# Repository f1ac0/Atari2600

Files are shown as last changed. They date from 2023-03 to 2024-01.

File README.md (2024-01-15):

# Atari2600
Inside the lot I bought to get my first C64 was also and Atari 2600. It was also listed as "Untested", and it was obviously salvaged from a flood considering the mud and rust that was inside the case. It came without any game or accessory.

While waiting for the system to dry after a complete clean and rust removal I found the useful projects below to help me start with this system I didn't know anything about.
- First I needed some game so I put together a ROM cartridge on a breadboard and created a PCB from it.
- Then not a single TV receiver I had could tune the video and audio signals correctly, but a BT848 PCTV PCI card. The mod by Eddy Foucault worked perfectly, I made my own version with CMS components and 5v only.
- At last I removed the regulator to power the console from a modern 5V power source.

In this repository are the PCBs I created or modified for my own needs.

# Disclaimer and Acknowledgements
This is a hobbyist project, it comes with no warranty and no support. Also remember that the 40 years old hardware may fail because of such expansions.

I publish my work under the CC-BY-NC-SA license, unless stated otherwise. Thanks to everyone who share their knowledge and creations.

# Useful links

## Cartridge
- https://github.com/sarweiler/a2k6-cart
- https://github.com/robinhedwards/UnoCart-2600
- https://github.com/DirtyHairy/UnoCart-2600/releases
- https://github.com/rglenn/unocart2600-pcb
- https://github.com/Al-Nafuur/United-Carts-of-Atari

## Video SECAM Atari 2600 to RGB SCART TV
- http://eddystoys.blogspot.com/2014/08/atari-2600.html

## Video SECAM to PAL
- https://forums.atariage.com/topic/245189-converting-a-secam-atari-2600-to-pal-or-ntsc/

## Video PAL/NTSC to composite
- https://www.arcticretro.com/2021/03/27/atari-2600-composite-video-mod/
- https://www.instructables.com/ATARI-2600-Video-Composite-mod/

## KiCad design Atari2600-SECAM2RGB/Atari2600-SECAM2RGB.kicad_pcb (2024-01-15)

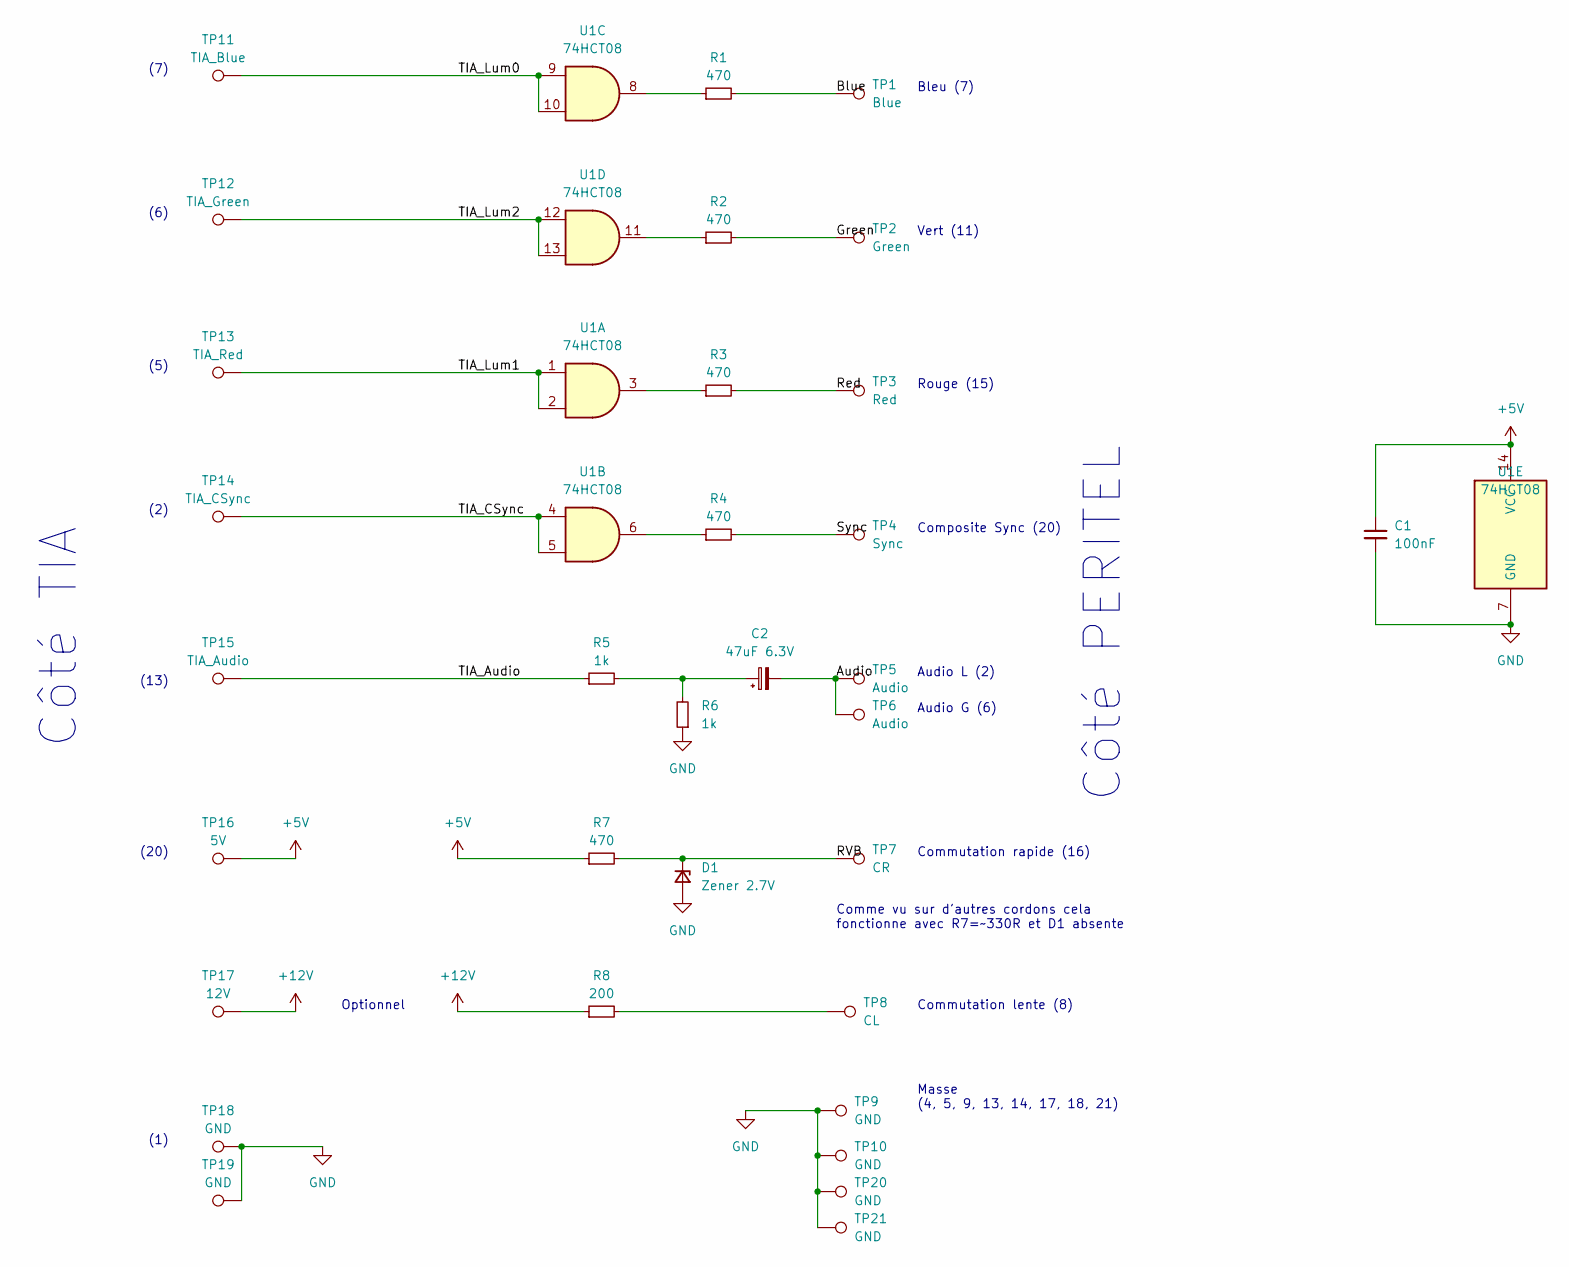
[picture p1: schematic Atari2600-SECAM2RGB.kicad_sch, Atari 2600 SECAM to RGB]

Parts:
C1: 100nF; C_0805_2012Metric
C2: 47uF 6.3V; CP_Elec_6.3x5.4
D1: Zener 2.7V; D_0805_2012Metric
R1, R2, R3, R4, R7: 470; R_0805_2012Metric
R5, R6: 1k; R_0805_2012Metric
R8: 200; R_0805_2012Metric
TP1: Blue; TestPoint_THTPad_D1.7mm_Drill1.0mm
TP2: Green; TestPoint_THTPad_D1.7mm_Drill1.0mm
TP3: Red; TestPoint_THTPad_D1.7mm_Drill1.0mm
TP4: Sync; TestPoint_THTPad_D1.7mm_Drill1.0mm
TP5, TP6: Audio; TestPoint_THTPad_D1.7mm_Drill1.0mm
TP7: CR; TestPoint_THTPad_D1.7mm_Drill1.0mm
TP8: CL; TestPoint_THTPad_D1.7mm_Drill1.0mm
TP9, TP10, TP18, TP19, TP20, TP21: GND; TestPoint_THTPad_D1.7mm_Drill1.0mm
TP11: TIA_Blue; TestPoint_THTPad_D1.7mm_Drill1.0mm
TP12: TIA_Green; TestPoint_THTPad_D1.7mm_Drill1.0mm
TP13: TIA_Red; TestPoint_THTPad_D1.7mm_Drill1.0mm
TP14: TIA_CSync; TestPoint_THTPad_D1.7mm_Drill1.0mm
TP15: TIA_Audio; TestPoint_THTPad_D1.7mm_Drill1.0mm
TP16: 5V; TestPoint_THTPad_D1.7mm_Drill1.0mm
TP17: 12V; TestPoint_THTPad_D1.7mm_Drill1.0mm
U1: 74HCT08; SO-14_3.9x8.65mm_P1.27mm

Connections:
+5V: C1.1, R7.1, TP16.1, U1.14 (VCC)
+12V: R8.1, TP17.1
/Audio: C2.2, TP5.1, TP6.1
/Blue: R1.2, TP1.1
/Green: R2.2, TP2.1
/RVB: D1.1 (K), R7.2, TP7.1
/Red: R3.2, TP3.1
/Sync: R4.2, TP4.1
/TIA_Audio: R5.1, TP15.1
/TIA_CSync: TP14.1, U1.4, U1.5
/TIA_Lum0: TP11.1, U1.9, U1.10
/TIA_Lum1: TP13.1, U1.1, U1.2
/TIA_Lum2: TP12.1, U1.12, U1.13
GND: C1.2, D1.2 (A), R6.1, TP9.1, TP10.1, TP18.1, TP19.1, TP20.1, TP21.1, U1.7 (GND)
unnamed: C2.1, R5.2, R6.2
unnamed: R1.1, U1.8
unnamed: R2.1, U1.11
unnamed: R3.1, U1.3
unnamed: R4.1, U1.6
unnamed: R8.2, TP8.1

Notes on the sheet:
Vert (11)
Rouge (15)
Composite Sync (20)
(7)
Côté PERITEL
Audio G (6)
Bleu (7)
(13)
(1)
(20)
Audio L (2)
Optionnel
Côté TIA
(6)
Comme vu sur d'autres cordons cela fonctionne avec R7=~330R et D1 absente
(2)
Commutation rapide (16)
Masse (4, 5, 9, 13, 14, 17, 18, 21)
(5)
Commutation lente (8)

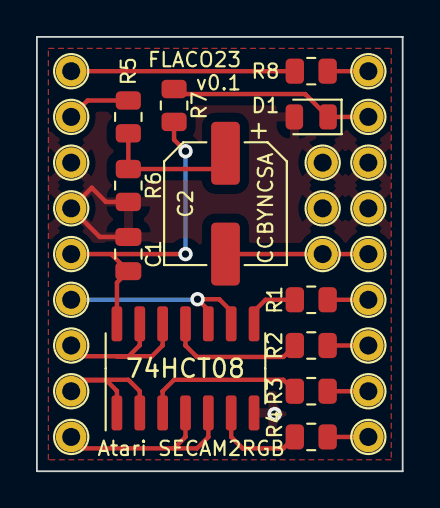
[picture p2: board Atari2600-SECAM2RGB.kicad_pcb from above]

Board: 2 copper layers, 20.3 x 24.1 mm, 33 parts (0 on the bottom side), 20 nets.

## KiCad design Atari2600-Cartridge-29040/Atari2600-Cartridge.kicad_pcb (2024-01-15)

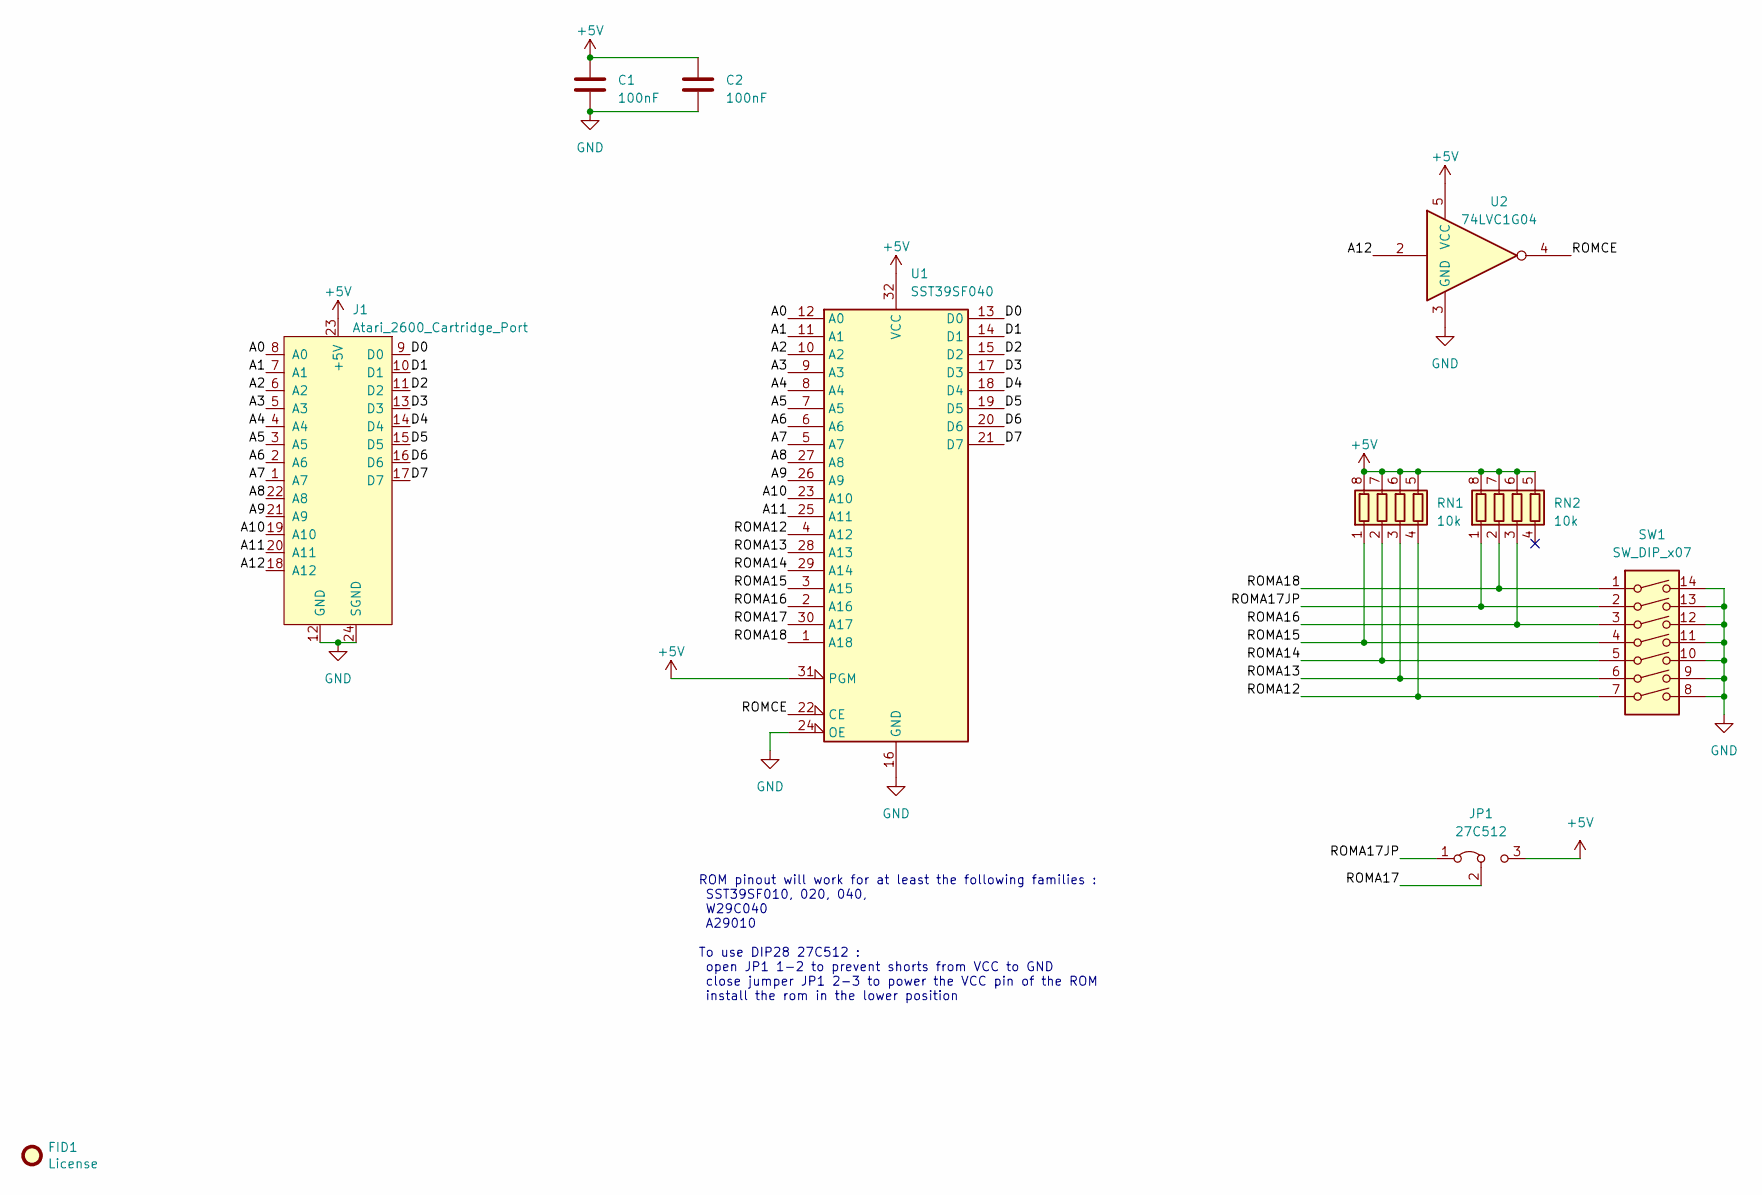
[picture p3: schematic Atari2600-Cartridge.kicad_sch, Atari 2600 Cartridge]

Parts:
C1, C2: 100nF; C_0805_2012Metric
FID1: License; CC_BY_NC_SA_square_silkscreen
J1: Atari_2600_Cartridge_Port; Atari2600_Cartridge_2x12_P2.54mm
JP1: 27C512; SolderJumper-3_P1.3mm_Bridged12_RoundedPad1.0x1.5mm
RN1, RN2: 10k; R_Array_Concave_4x0603
SW1: SW_DIP_x07; SW_DIP_SPSTx07_Slide_9.78x19.96mm_W7.62mm_P2.54mm
U1: SST39SF040; DIP-32_W15.24mm
U2: 74LVC1G04; SOT-23-5

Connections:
+5V: C1.1, C2.1, J1.23 (+5V), JP1.3 (B), RN1.5 (R4.2), RN1.6 (R3.2), RN1.7 (R2.2), RN1.8 (R1.2), RN2.5 (R4.2), RN2.6 (R3.2), RN2.7 (R2.2), RN2.8 (R1.2), U1.31 (PGM), U1.32 (VCC), U2.5 (VCC)
/A0: J1.8 (A0), U1.12 (A0)
/A1: J1.7 (A1), U1.11 (A1)
/A2: J1.6 (A2), U1.10 (A2)
/A3: J1.5 (A3), U1.9 (A3)
/A4: J1.4 (A4), U1.8 (A4)
/A5: J1.3 (A5), U1.7 (A5)
/A6: J1.2 (A6), U1.6 (A6)
/A7: J1.1 (A7), U1.5 (A7)
/A8: J1.22 (A8), U1.27 (A8)
/A9: J1.21 (A9), U1.26 (A9)
/A10: J1.19 (A10), U1.23 (A10)
/A11: J1.20 (A11), U1.25 (A11)
/A12: J1.18 (A12), U2.2
/D0: J1.9 (D0), U1.13 (D0)
/D1: J1.10 (D1), U1.14 (D1)
/D2: J1.11 (D2), U1.15 (D2)
/D3: J1.13 (D3), U1.17 (D3)
/D4: J1.14 (D4), U1.18 (D4)
/D5: J1.15 (D5), U1.19 (D5)
/D6: J1.16 (D6), U1.20 (D6)
/D7: J1.17 (D7), U1.21 (D7)
/ROMA12: RN1.4 (R4.1), SW1.7, U1.4 (A12)
/ROMA13: RN1.3 (R3.1), SW1.6, U1.28 (A13)
/ROMA14: RN1.2 (R2.1), SW1.5, U1.29 (A14)
/ROMA15: RN1.1 (R1.1), SW1.4, U1.3 (A15)
/ROMA16: RN2.3 (R3.1), SW1.3, U1.2 (A16)
/ROMA17: JP1.2 (C), U1.30 (A17)
/ROMA17JP: JP1.1 (A), RN2.1 (R1.1), SW1.2
/ROMA18: RN2.2 (R2.1), SW1.1, U1.1 (A18)
/ROMCE: U1.22 (CE), U2.4
GND: C1.2, C2.2, J1.12 (GND), J1.24 (SGND), SW1.8, SW1.9, SW1.10, SW1.11, SW1.12, SW1.13, SW1.14, U1.16 (GND), U1.24 (OE), U2.3 (GND)

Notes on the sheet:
ROM pinout will work for at least the following families : SST39SF010, 020, 040, W29C040 A29010 To use DIP28 27C512 : open JP1 1-2 to prevent shorts from VCC to GND close jumper JP1 2-3 to power the VCC pin of the ROM install the rom in the lower position

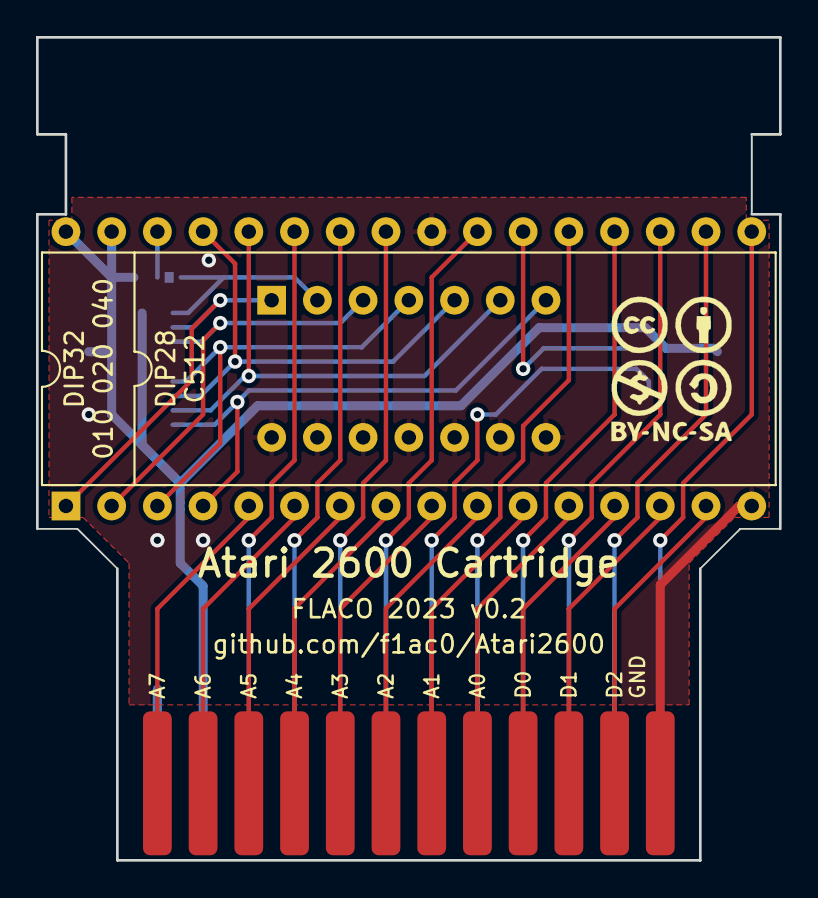
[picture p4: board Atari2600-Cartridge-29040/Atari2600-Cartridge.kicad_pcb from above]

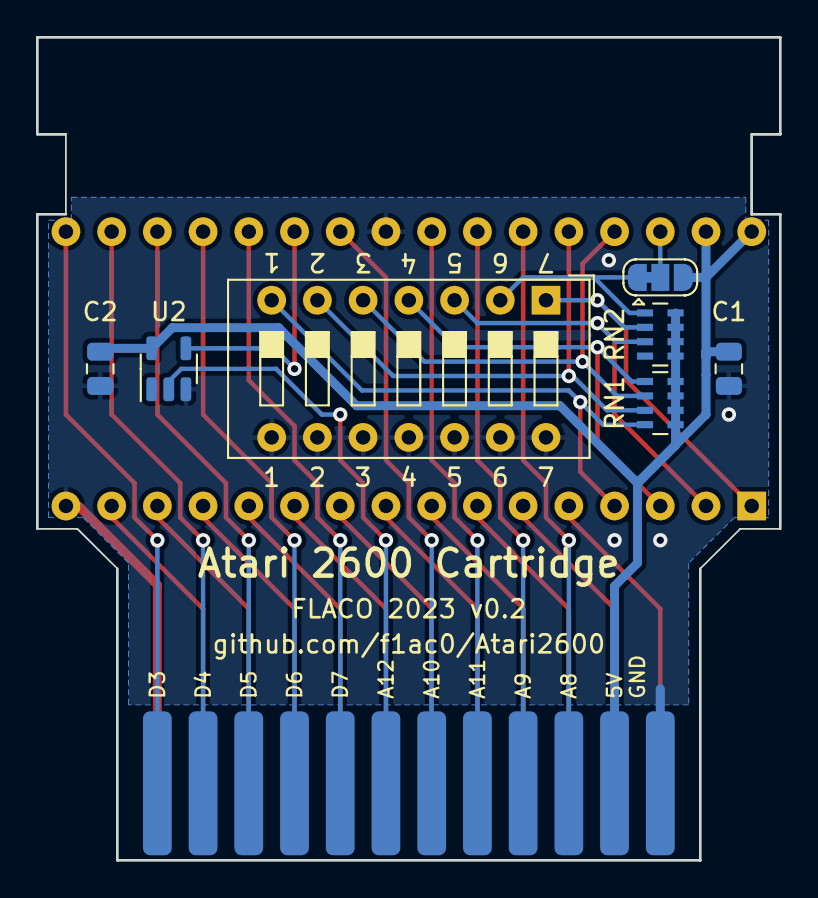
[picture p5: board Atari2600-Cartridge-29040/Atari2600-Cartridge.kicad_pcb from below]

Board: 2 copper layers, 41.3 x 45.7 mm, 10 parts (7 on the bottom side), 32 nets.

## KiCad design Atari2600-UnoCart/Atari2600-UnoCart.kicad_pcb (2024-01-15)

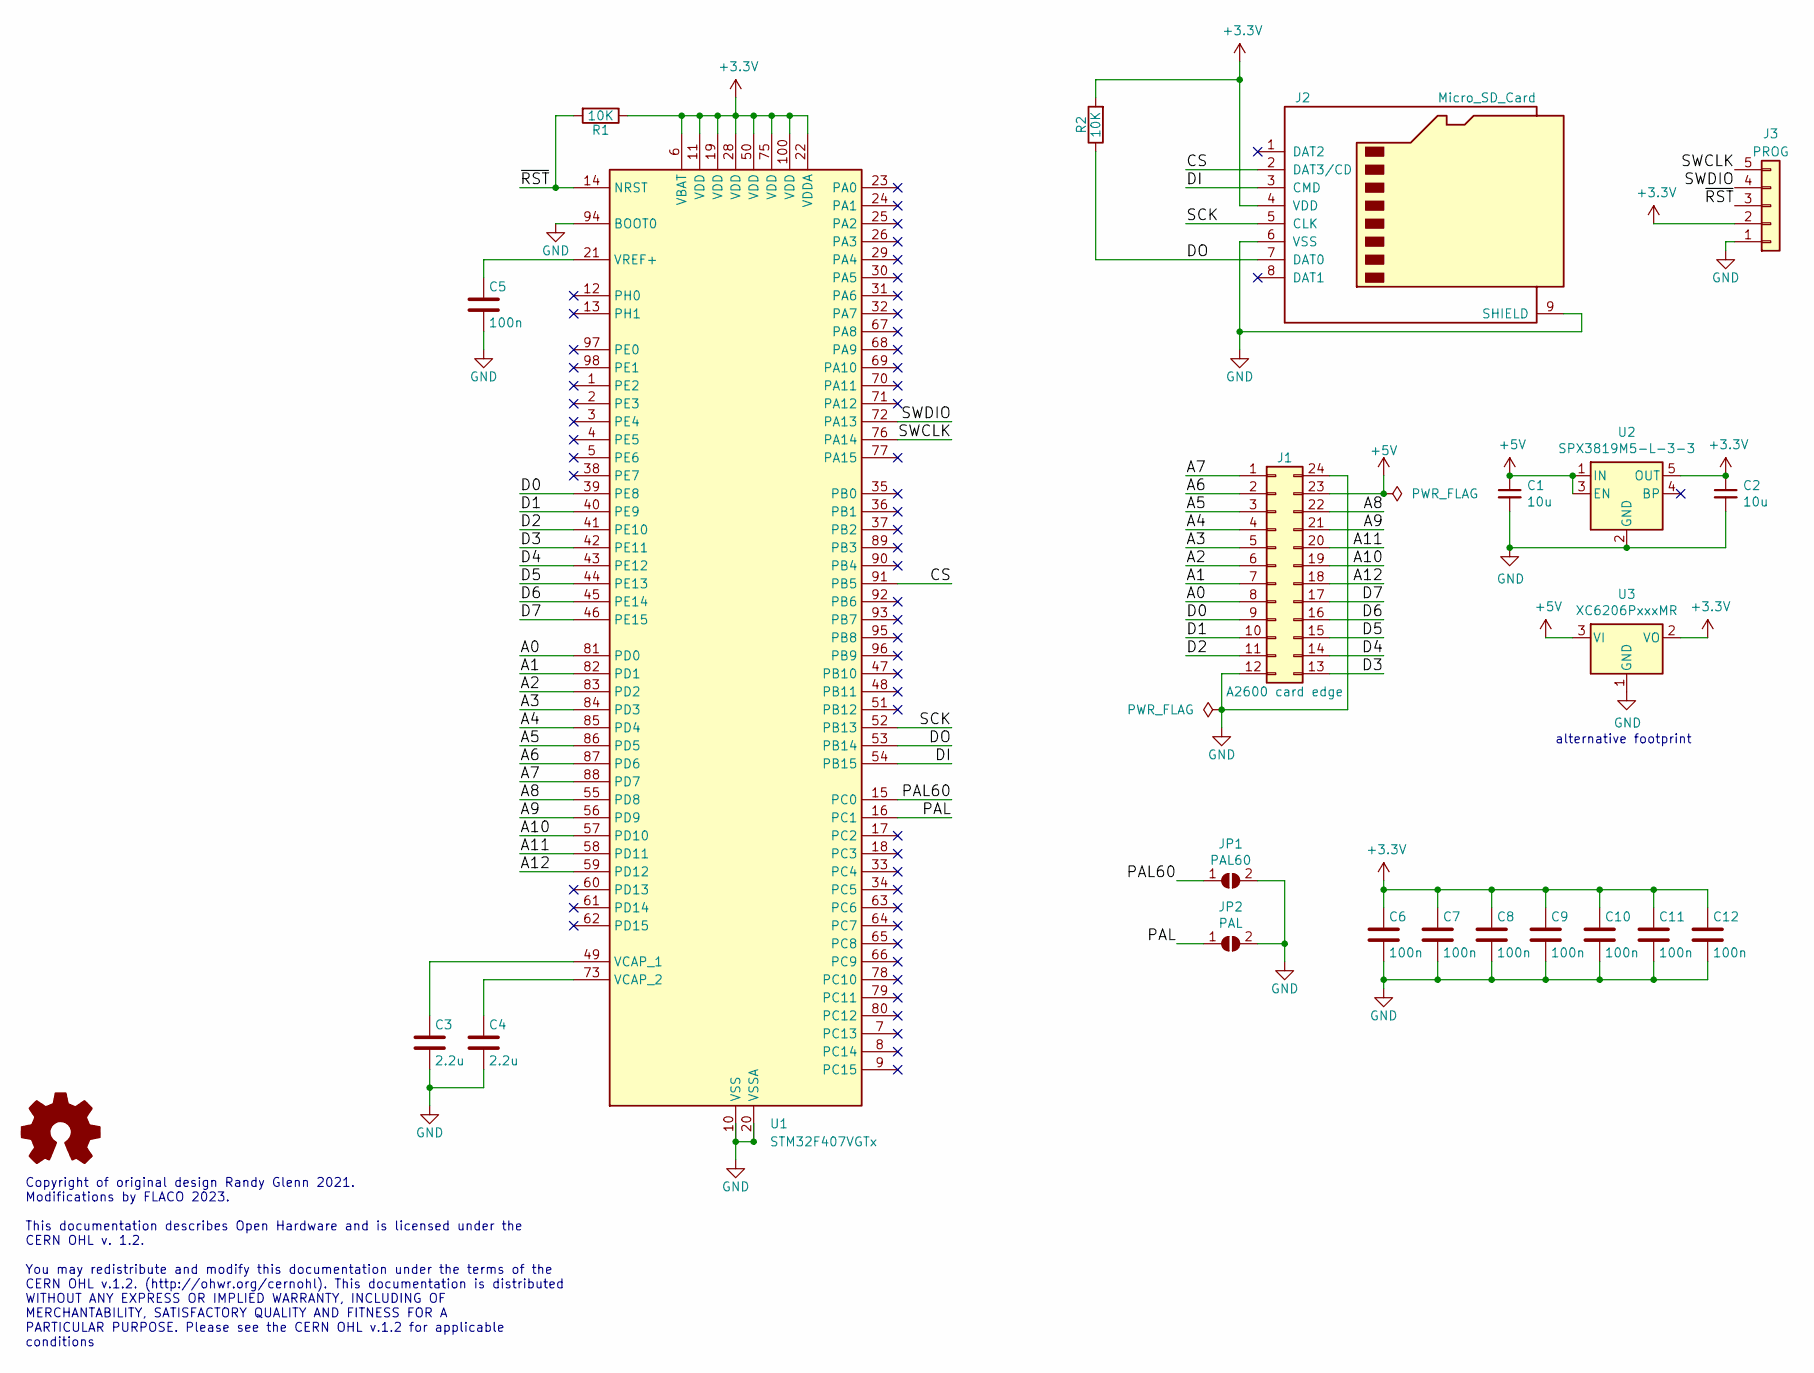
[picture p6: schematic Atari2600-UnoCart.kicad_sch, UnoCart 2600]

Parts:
C1, C2: 10u; C_0805_2012Metric
C3, C4: 2.2u; C_0805_2012Metric
C5, C6, C7, C8, C9, C10, C11, C12: 100n; C_0805_2012Metric
J1: A2600 card edge; Atari2600_Cartridge_2x12_P2.54mm
J2: Micro_SD_Card; TFP09-2-12B
J3: PROG; PinHeader_1x05_P2.54mm_Vertical
JP1: PAL60; SolderJumper-2_P1.3mm_Open_RoundedPad1.0x1.5mm
JP2: PAL; SolderJumper-2_P1.3mm_Open_RoundedPad1.0x1.5mm
R1, R2: 10K; R_0805_2012Metric
U1: STM32F407VGTx; LQFP-100_14x14mm_P0.5mm
U2: SPX3819M5-L-3-3; SOT-23-5
U3: XC6206PxxxMR; SOT-23

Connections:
+3.3V: C2.1, C6.1, C7.1, C8.1, C9.1, C10.1, C11.1, C12.1, J2.4 (VDD), J3.2, R1.1, R2.2, U1.6 (VBAT), U1.11 (VDD), U1.19 (VDD), U1.22 (VDDA), U1.28 (VDD), U1.50 (VDD), U1.75 (VDD), U1.100 (VDD), U2.5 (OUT), U3.2 (VO)
+5V: C1.1, J1.23, U2.1 (IN), U2.3 (EN), U3.3 (VI)
/A0: J1.8, U1.81 (PD0)
/A1: J1.7, U1.82 (PD1)
/A2: J1.6, U1.83 (PD2)
/A3: J1.5, U1.84 (PD3)
/A4: J1.4, U1.85 (PD4)
/A5: J1.3, U1.86 (PD5)
/A6: J1.2, U1.87 (PD6)
/A7: J1.1, U1.88 (PD7)
/A8: J1.22, U1.55 (PD8)
/A9: J1.21, U1.56 (PD9)
/A10: J1.19, U1.57 (PD10)
/A11: J1.20, U1.58 (PD11)
/A12: J1.18, U1.59 (PD12)
/CS: J2.2 (DAT3/CD), U1.91 (PB5)
/D0: J1.9, U1.39 (PE8)
/D1: J1.10, U1.40 (PE9)
/D2: J1.11, U1.41 (PE10)
/D3: J1.13, U1.42 (PE11)
/D4: J1.14, U1.43 (PE12)
/D5: J1.15, U1.44 (PE13)
/D6: J1.16, U1.45 (PE14)
/D7: J1.17, U1.46 (PE15)
/DI: J2.3 (CMD), U1.54 (PB15)
/DO: J2.7 (DAT0), R2.1, U1.53 (PB14)
/PAL: JP2.1 (A), U1.16 (PC1)
/PAL60: JP1.1 (A), U1.15 (PC0)
/SCK: J2.5 (CLK), U1.52 (PB13)
/SWCLK: J3.5, U1.76 (PA14)
/SWDIO: J3.4, U1.72 (PA13)
/~RST: J3.3, R1.2, U1.14 (NRST)
GND: C1.2, C2.2, C3.2, C4.2, C5.2, C6.2, C7.2, C8.2, C9.2, C10.2, C11.2, C12.2, J1.12, J1.24, J2.6 (VSS), J2.9 (SHIELD), J3.1, JP1.2 (B), JP2.2 (B), U1.10 (VSS), U1.20 (VSSA), U1.27 (VSS), U1.74 (VSS), U1.94 (BOOT0), U1.99 (VSS), U2.2 (GND), U3.1 (GND)
unnamed: C3.1, U1.49 (VCAP_1)
unnamed: C4.1, U1.73 (VCAP_2)
unnamed: C5.1, U1.21 (VREF+)

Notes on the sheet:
Copyright of original design Randy Glenn 2021. Modifications by FLACO 2023. This documentation describes Open Hardware and is licensed under the CERN OHL v. 1.2. You may redistribute and modify this documentation under the terms of the CERN OHL v.1.2. (http://ohwr.org/cernohl). This documentation i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
alternative footprint

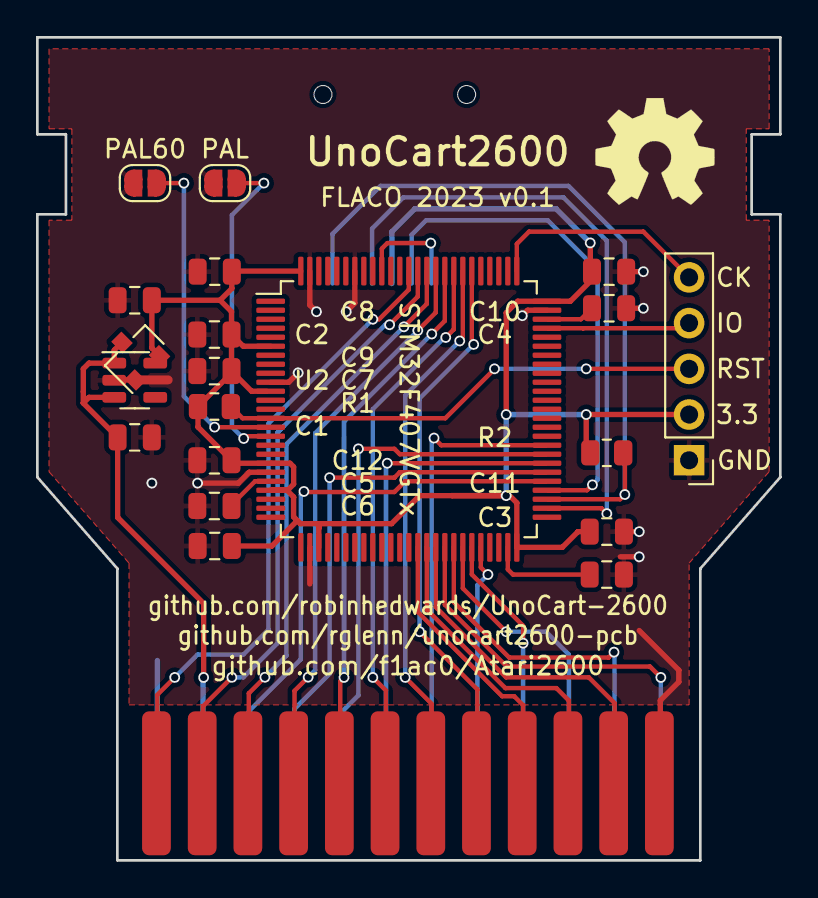
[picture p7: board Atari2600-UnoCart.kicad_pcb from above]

Board: 2 copper layers, 41.3 x 45.7 mm, 22 parts (1 on the bottom side), 36 nets.

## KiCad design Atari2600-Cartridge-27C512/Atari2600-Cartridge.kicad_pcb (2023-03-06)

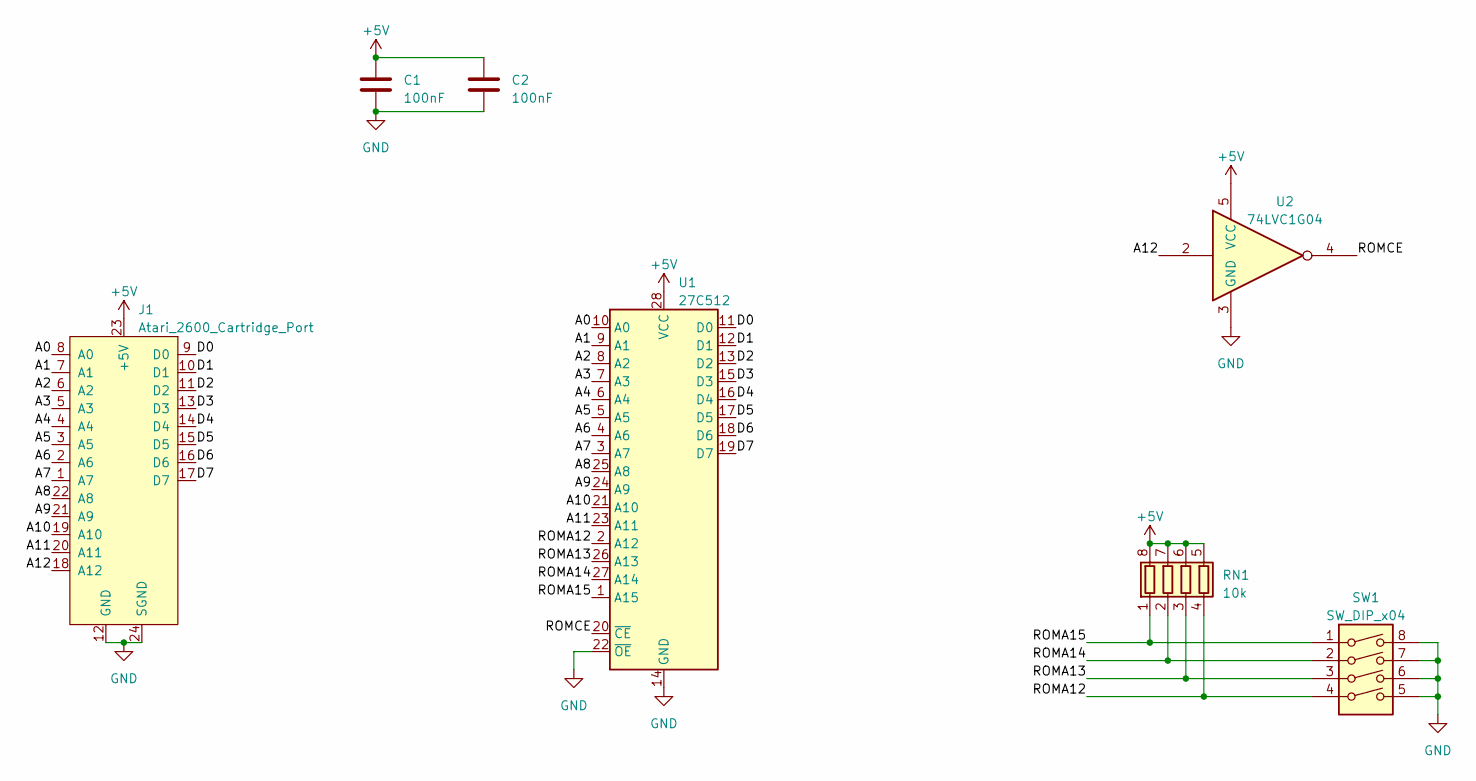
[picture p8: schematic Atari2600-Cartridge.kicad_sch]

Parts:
C1, C2: 100nF; C_0805_2012Metric
J1: Atari_2600_Cartridge_Port; Atari2600_Cartridge_2x12_P2.54mm
RN1: 10k; R_Array_Concave_4x0603
SW1: SW_DIP_x04; SW_DIP_SPSTx04_Slide_9.78x12.34mm_W7.62mm_P2.54mm
U1: 27C512; DIP-28_W15.24mm
U2: 74LVC1G04; SOT-23-5

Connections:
+5V: C1.1, C2.1, J1.23 (+5V), RN1.5 (R4.2), RN1.6 (R3.2), RN1.7 (R2.2), RN1.8 (R1.2), U1.28 (VCC), U2.5 (VCC)
/A0: J1.8 (A0), U1.10 (A0)
/A1: J1.7 (A1), U1.9 (A1)
/A2: J1.6 (A2), U1.8 (A2)
/A3: J1.5 (A3), U1.7 (A3)
/A4: J1.4 (A4), U1.6 (A4)
/A5: J1.3 (A5), U1.5 (A5)
/A6: J1.2 (A6), U1.4 (A6)
/A7: J1.1 (A7), U1.3 (A7)
/A8: J1.22 (A8), U1.25 (A8)
/A9: J1.21 (A9), U1.24 (A9)
/A10: J1.19 (A10), U1.21 (A10)
/A11: J1.20 (A11), U1.23 (A11)
/A12: J1.18 (A12), U2.2
/D0: J1.9 (D0), U1.11 (D0)
/D1: J1.10 (D1), U1.12 (D1)
/D2: J1.11 (D2), U1.13 (D2)
/D3: J1.13 (D3), U1.15 (D3)
/D4: J1.14 (D4), U1.16 (D4)
/D5: J1.15 (D5), U1.17 (D5)
/D6: J1.16 (D6), U1.18 (D6)
/D7: J1.17 (D7), U1.19 (D7)
/ROMA12: RN1.4 (R4.1), SW1.4, U1.2 (A12)
/ROMA13: RN1.3 (R3.1), SW1.3, U1.26 (A13)
/ROMA14: RN1.2 (R2.1), SW1.2, U1.27 (A14)
/ROMA15: RN1.1 (R1.1), SW1.1, U1.1 (A15)
/ROMCE: U1.20 (~CE), U2.4
GND: C1.2, C2.2, J1.12 (GND), J1.24 (SGND), SW1.5, SW1.6, SW1.7, SW1.8, U1.14 (GND), U1.22 (~OE), U2.3 (GND)

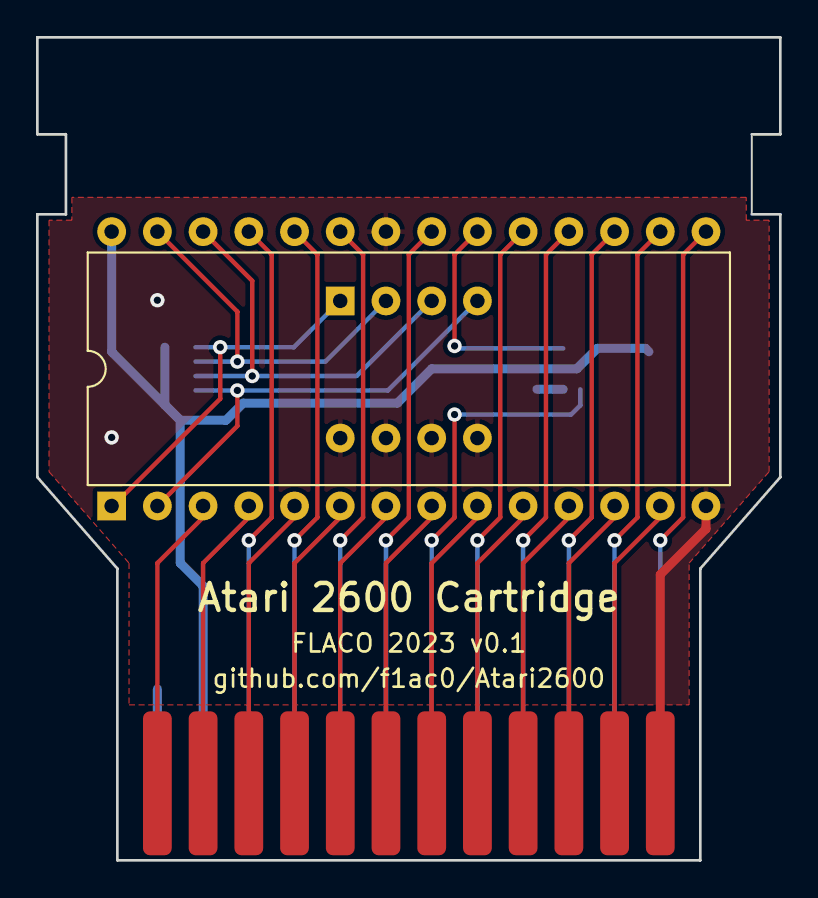
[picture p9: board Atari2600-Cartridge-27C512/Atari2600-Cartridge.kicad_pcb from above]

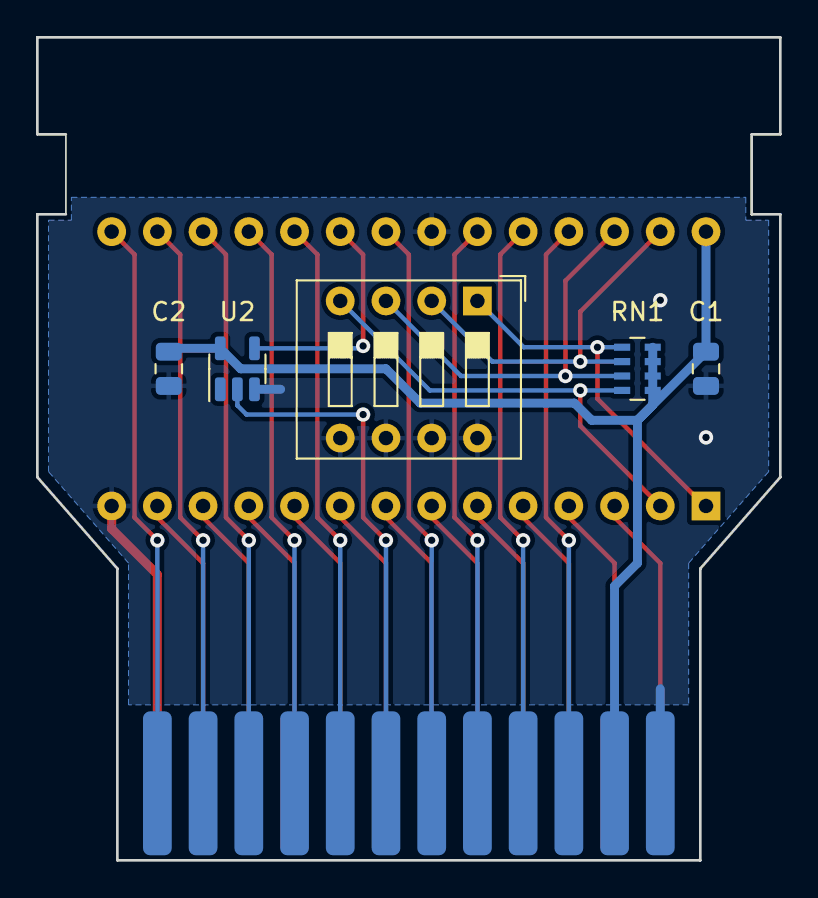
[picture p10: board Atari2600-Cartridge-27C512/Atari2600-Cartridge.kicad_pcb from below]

Board: 2 copper layers, 41.3 x 45.7 mm, 7 parts (5 on the bottom side), 28 nets.

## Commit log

2023-03-06 Respository init with KiCAD files, Readme and License
    [Atari2600-Cartridge.kicad_pcb, Atari2600-Cartridge.kicad_sch, Atari2600-UnoCart.kicad_pcb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]
2023-05-30 Addition of Atari2600-Cartridge-29040 to support DIP32 EEPROMs. Addition of Interactive Boms.
    [Atari2600-Cartridge.kicad_pcb, Atari2600-Cartridge.kicad_sch, Atari2600-UnoCart.kicad_pcb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]
2024-01-15 Addition of Atari2600-SECAM2RGB ; update license of Atari2600-UnoCart and README.
    [Atari2600-Cartridge.kicad_pcb, Atari2600-SECAM2RGB.kicad_pcb, Atari2600-SECAM2RGB.kicad_sch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]

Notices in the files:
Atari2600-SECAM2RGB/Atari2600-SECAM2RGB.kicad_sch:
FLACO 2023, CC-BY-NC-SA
